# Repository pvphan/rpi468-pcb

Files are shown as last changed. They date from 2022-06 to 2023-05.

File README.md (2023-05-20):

'Raspberry Pi 468' PCB files
---

This repo contains the PCB model files for the RPi 468
For more details, see my blog post here: [pvphan.com](https://pvphan.com)

Links to these PCB projects on OSHPark:
- [USB host switching circuit](https://oshpark.com/shared_projects/PfGfJg1X)
- [Mini USB pad to JST](https://oshpark.com/shared_projects/LUSGZfi8)

The USB host switching circuit solder in place of the Raspberry Pi 400 USB-A 2.0 port
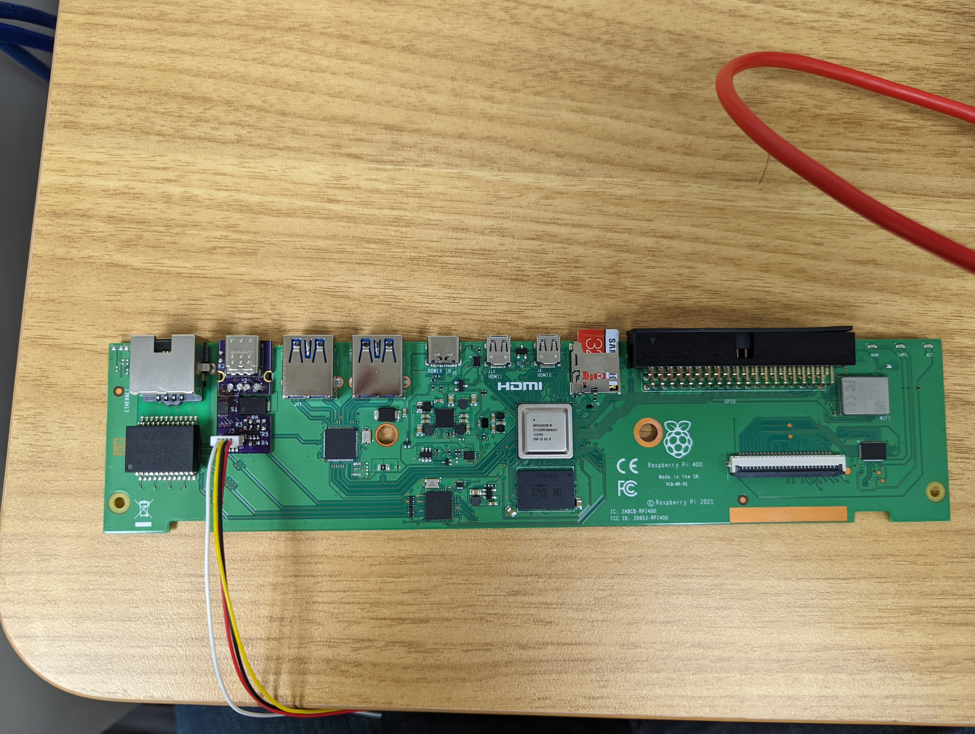
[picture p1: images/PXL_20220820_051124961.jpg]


The USB host switching circuit, mostly soldered
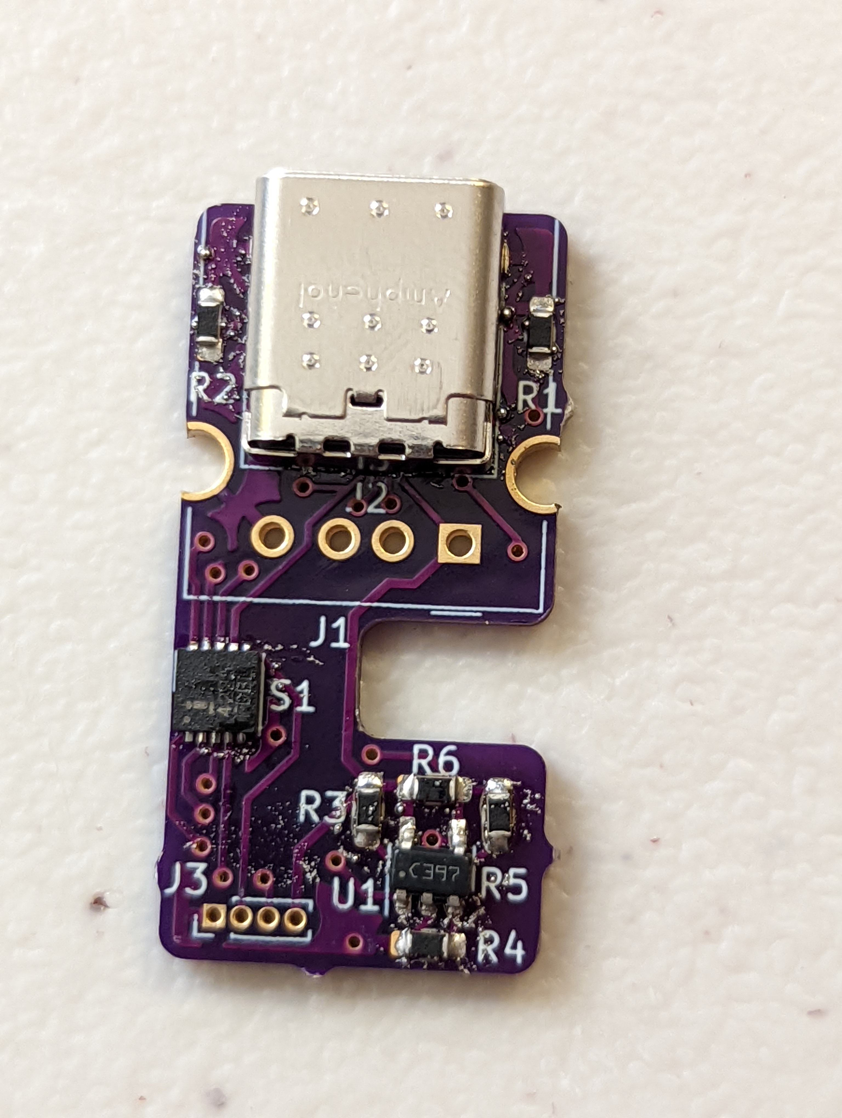
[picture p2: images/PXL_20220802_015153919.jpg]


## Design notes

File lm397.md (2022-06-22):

LM397 Comparator
---

Datasheet: https://www.ti.com/lit/ds/symlink/lm397.pdf

Compares an input voltage V_IN at the noninverting pin
to the reference voltage V_REF at the inverting pin.

If V_IN is less than V_REF, the output V_O is low (V_OL)
Else if V_IN is greater than V_REF the output voltage V_O is high (V_OH)

For this use case:
    V_REF = 0V = GND
    V_IN = CC1 ~= 0.19V
    V_OH = 5V

Input stage: bipolar
Output stage: open-collector ground-emitter NPN output transistor, meaning it needs a pull-up resistor tied between V_S and OUTPUT.

Since the desired threshold voltage and reference are close (0.0 vs 0.19 V), we will add hysteresis to prevent the problem of switching spurriously. This creates two switching thresholds:
- One for the rising input voltage
- One for the falling input voltage

For an inverting configured comparator, hysteresis can be added with a three resistor network and positive feedback.
When the input voltage (V_IN) at the inverting node is less than the non-inverting node (V_T), the output is high.

The lower threshold voltage V_T1 is calculated by Equation 1:

    V_T1 = ((V_S * R2) / (((R1 * R3) / (R1 + R3)) + R2))

When V_IN is greater than V_T, the ouput voltage is low.
The upper threshold voltage V_T2 is calculated by Equation 2:

    V_T2 = V_S * ((R2 * R3) / (R2 + R3)) / (R1 + ((R2 * R3) / (R2 + R3)))

The hysteresis is defined in Equation 3:

    ΔV_IN = V_T1 - V_T2

Design example: Inverting comparator with hysteresis

Let's say:

    V_T2 = 0.05 V
    V_T1 = 0.15 V
    --> ΔV_IN  = 0.10 V

Need to determine:
- Input voltage range: 0.0 V to V_S - 1.5 V
    --> 0.0V to 3.5 V
    this seems fine if we can use 0.0 V as reference and 0.19 V as the signal for 'high'

- Minimum overdrive voltage:
    This is the differential betwwen the positive and negative inputs on the comparator over the offset voltage.

- Output and drive current:

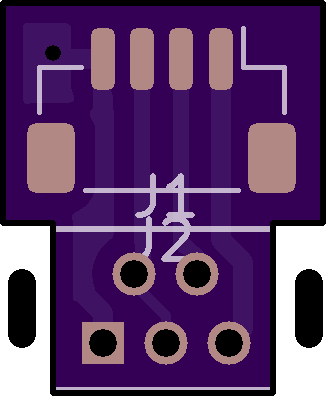
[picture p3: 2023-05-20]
images/13abb42a9bf6000eb30251c35fe534aa.png

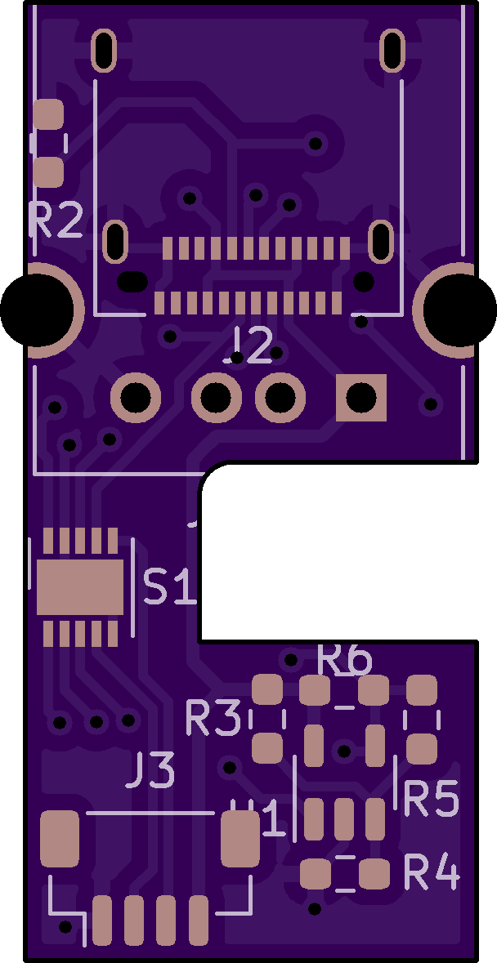
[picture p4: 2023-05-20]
images/31ba4bf55e1f18116c7da5aad2c9d18b.png

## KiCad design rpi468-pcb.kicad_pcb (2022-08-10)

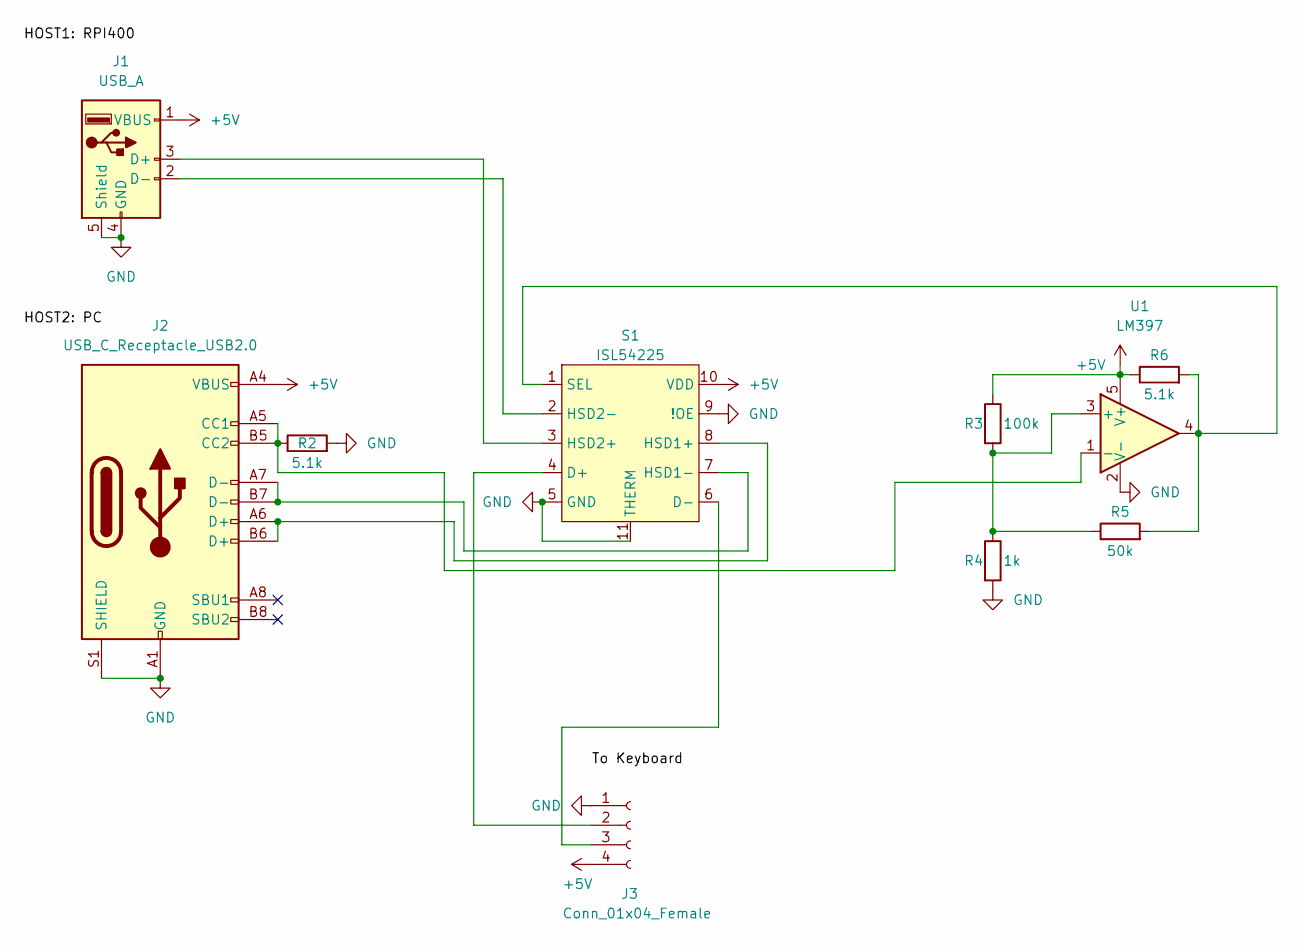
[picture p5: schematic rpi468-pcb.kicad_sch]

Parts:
J1: USB_A; USB_A_Molex_67643_Horizontal
J2: USB_C_Receptacle_USB2.0; USB_C_Receptacle_Amphenol_12401610E4-2A
J3: Conn_01x04_Female; JST_SH_BM04B-SRSS-TB_1x04-1MP_P1.00mm_Vertical
R2, R6: 5.1k; R_0603_1608Metric_Pad0.98x0.95mm_HandSolder
R3: 100k; R_0603_1608Metric_Pad0.98x0.95mm_HandSolder
R4: 1k; R_0603_1608Metric_Pad0.98x0.95mm_HandSolder
R5: 50k; R_0603_1608Metric_Pad0.98x0.95mm_HandSolder
S1: ISL54225; DFN-10-1EP_3x3mm_P0.5mm_EP1.75x2.7mm
U1: LM397; SOT-23-5

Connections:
+5V: J1.1 (VBUS), J2.A4 (VBUS), J2.A9 (VBUS), J2.B4 (VBUS), J2.B9 (VBUS), J3.4, R3.1, R6.1, S1.10 (VDD), U1.5 (V+)
GND: J1.4 (GND), J1.5 (Shield), J2.A1 (GND), J2.A12 (GND), J2.B1 (GND), J2.B12 (GND), J2.S1 (SHIELD), J3.1, R2.2, R4.2, S1.5 (GND), S1.9 (!OE), S1.11 (THERM), U1.2 (V-)
unnamed: J1.2 (D-), S1.2 (HSD2-)
unnamed: J1.3 (D+), S1.3 (HSD2+)
unnamed: J2.A5 (CC1), J2.B5 (CC2), R2.1, U1.1 (-)
unnamed: J2.A6 (D+), J2.B6 (D+), S1.8 (HSD1+)
unnamed: J2.A7 (D-), J2.B7 (D-), S1.7 (HSD1-)
unnamed: R3.2, R4.1, R5.1, U1.3 (+)
unnamed: R5.2, R6.2, S1.1 (SEL), U1.4
unnamed: J3.2, S1.4 (D+)
unnamed: J3.3, S1.6 (D-)

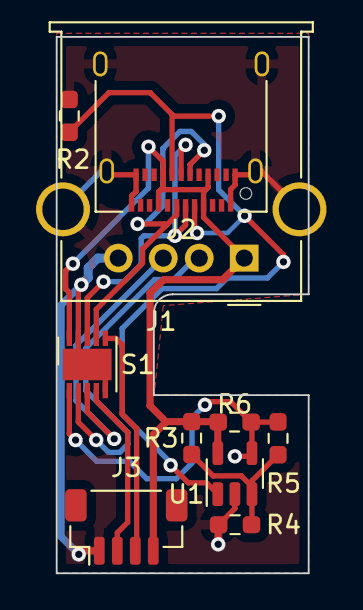
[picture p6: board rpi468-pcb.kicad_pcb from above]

Board: 2 copper layers, 14.0 x 29.8 mm, 10 parts (0 on the bottom side), 11 nets.

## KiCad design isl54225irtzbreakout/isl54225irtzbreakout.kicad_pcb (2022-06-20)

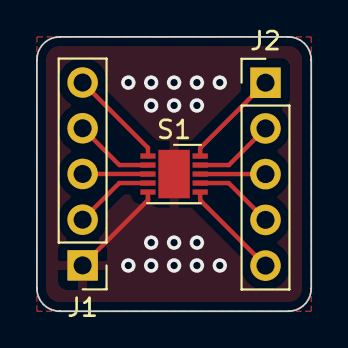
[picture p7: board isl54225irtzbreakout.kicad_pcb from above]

Board: 2 copper layers, 15.2 x 15.2 mm, 3 parts (0 on the bottom side), 10 nets.

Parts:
J1, J2: Conn_01x05; PinHeader_1x05_P2.54mm_Vertical
S1: ISL54225; DFN-10-1EP_3x3mm_P0.5mm_EP1.75x2.7mm

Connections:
GND: J1.1, S1.5 (GND), S1.11 (THERM)
unnamed: J1.2, S1.4 (D+)
unnamed: J1.3, S1.3 (HSD2+)
unnamed: J1.4, S1.2 (HSD1+)
unnamed: J1.5, S1.1 (SEL)
unnamed: J2.1, S1.10 (VDD)
unnamed: J2.2, S1.9 (!OE)
unnamed: J2.3, S1.8 (HSD1-)
unnamed: J2.4, S1.7 (HSD2-)
unnamed: J2.5, S1.6 (D-)

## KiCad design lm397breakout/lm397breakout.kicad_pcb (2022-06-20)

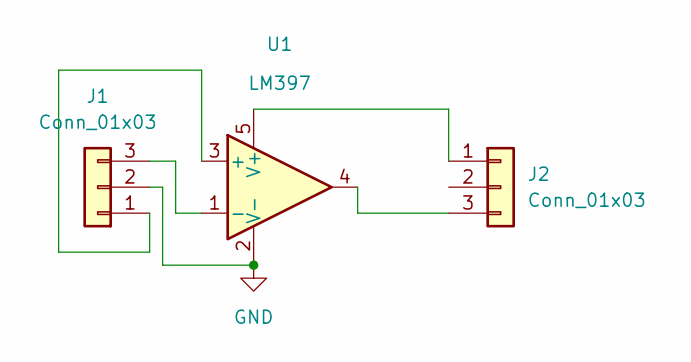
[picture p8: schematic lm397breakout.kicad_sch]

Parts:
J1: Conn_01x03
J2: Conn_01x03; PinHeader_1x03_P2.54mm_Vertical
U1: LM397; SOT-23-5

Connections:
GND: J1.2, U1.2 (V-)
unnamed: J1.1, U1.3 (+)
unnamed: J1.3, U1.1 (-)
unnamed: J2.1, U1.5 (V+)
unnamed: J2.3, U1.4

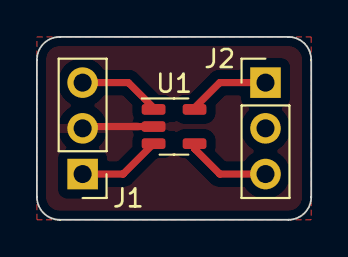
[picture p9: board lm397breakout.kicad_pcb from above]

Board: 2 copper layers, 15.2 x 10.2 mm, 3 parts (0 on the bottom side), 5 nets.

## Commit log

2022-06-07 commiting files
    [rpi468-pcb.kicad_pcb, rpi468-pcb.kicad_sch]
2022-06-20 added breakout boardk
    [lm397breakout.kicad_pcb, lm397breakout.kicad_sch, rpi468-pcb.kicad_sch]
2022-06-20 rounded edges of breakout
    [lm397breakout.kicad_pcb, lm397breakout.kicad_sch]
2022-06-20 added new breakout for ISL54225
    [isl54225irtzbreakout.kicad_pcb, isl54225irtzbreakout.kicad_sch]
2022-06-22 reasonable resistor values
2022-06-23 started layout
    [rpi468-pcb.kicad_pcb, rpi468-pcb.kicad_sch]
2022-06-23 moved some components
    [rpi468-pcb.kicad_pcb]
2022-06-24 trying to route
    [rpi468-pcb.kicad_pcb]
2022-07-06 fixed bug, schematic works for breadboard
    [rpi468-pcb.kicad_sch]
2022-07-06 layingout the board again
    [rpi468-pcb.kicad_pcb, rpi468-pcb.kicad_sch]
2022-07-06 updated layout a little
    [rpi468-pcb.kicad_pcb]
2022-07-06 made some tracks
    [rpi468-pcb.kicad_pcb]
2022-07-08 routing seems more reasonable, still need to refer to mCAD for actual cut profile
    [rpi468-pcb.kicad_pcb]
2022-07-08 cleaned up some traces
    [rpi468-pcb.kicad_pcb]
2022-07-21 added outline
    [rpi468-pcb.kicad_pcb]
2022-07-22 routing close to done
    [rpi468-pcb.kicad_pcb]
2022-07-22 finished routing
    [rpi468-pcb.kicad_pcb]
2022-07-22 updated board for 1mm pitch connector, reran some traces
    [rpi468-pcb.kicad_pcb, rpi468-pcb.kicad_sch]
2022-07-22 some cleanup
    [rpi468-pcb.kicad_pcb]
2022-07-27 added usb-c to model
    [rpi468-pcb.kicad_pcb]
2022-08-07 bridging CC1 and CC2
    [rpi468-pcb.kicad_sch]
2022-08-10 updated pcb
    [rpi468-pcb.kicad_pcb, rpi468-pcb.kicad_sch]
2022-08-10 ignoring cad files
2022-08-10 updated cut outline
    [rpi468-pcb.kicad_pcb]
2022-08-11 added note
    [rpi468-pcb.kicad_sch]
2022-08-13 added connector board
    [miniusb-jst.kicad_pcb, miniusb-jst.kicad_sch]
